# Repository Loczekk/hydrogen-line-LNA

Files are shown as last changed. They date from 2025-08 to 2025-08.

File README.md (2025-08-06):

PL below
<!-- TABLE OF CONTENTS -->

<details> <summary>Table of Contents</summary> 
  <ol> 
    <li><a href="#introduction">Introduction</a></li> 
    <li><a href="#final-parameters">Final Parameters</a></li> 
    <li><a href="#measurements">Measurements</a></li> 
  </ol> 
</details>
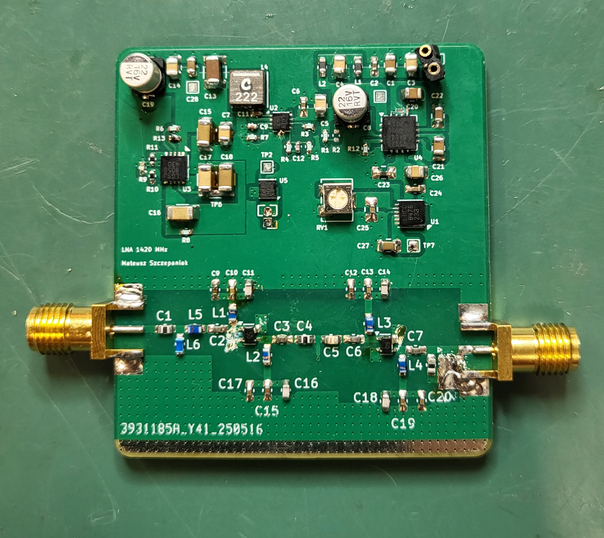
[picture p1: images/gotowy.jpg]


<!-- INTRODUCTION -->
## Introduction
The aim of the project was to design, build and test a low noise amplifier operating in the L-band. The amplifier was to meet strict requirements for gain (> 30 dB) and noise figure less than 1 dB.
A two-stage amplifier was implemented as a PCB on RF4 laminate and then subjected to detailed measurements to verify its performance. Scattering parameters, noise figure, 1 dB compression point, harmonic and third-order intermodulation distortion were measured.
Based on the results, it was concluded that the amplifier meets most of the design requirements: gain of 35.15 dB, output matching of 12.68 dB and 1-dB compression point at 3.02 dBm. Only the noise figure exceeded the assumed value and reached 1.39 dB, which, however, does not disqualify it from applications in radio astronomy.
Additionally, an automatic biasing circuit for the LNA was designed to ensure the correct power-up voltage sequence.
<p align="right">(<a href="#readme-top">back to top</a>)</p>

## Final Parameters
<h3>Key Parameters (for <strong>f = 1420 MHz</strong>)</h3>

<table>
  <thead>
    <tr>
      <th>Parameter</th>
      <th>Value</th>
      <th>Requirement</th>
    </tr>
  </thead>
  <tbody>
    <tr>
      <td>Gain</td>
      <td>35.15 dB</td>
      <td>&gt; 30 dB</td>
    </tr>
    <tr>
      <td>Noise figure</td>
      <td>1.39 dB</td>
      <td>&lt; 1 dB</td>
    </tr>
    <tr>
      <td>Output matching (<i>S<sub>22</sub></i>)</td>
      <td>12.68 dB</td>
      <td>&gt; 10 dB</td>
    </tr>
    <tr>
      <td>Compression point (<i>P<sub>1dB</sub></i>)</td>
      <td>3.02 dBm</td>
      <td>&gt; 0 dBm</td>
    </tr>
    <tr>
      <td>THD (for <i>P<sub>IN</sub></i> = –40 dBm)</td>
      <td>–47.21 dB</td>
      <td>–</td>
    </tr>
    <tr>
      <td>IP3 (for <i>P<sub>IN</sub></i> = –40 dBm)</td>
      <td>19.09 dBm</td>
      <td>–</td>
    </tr>
  </tbody>
</table>
<p align="right">(<a href="#readme-top">back to top</a>)</p>

## Measurements
<h3>S11 and S22 parameters to compare with simulate</h3>
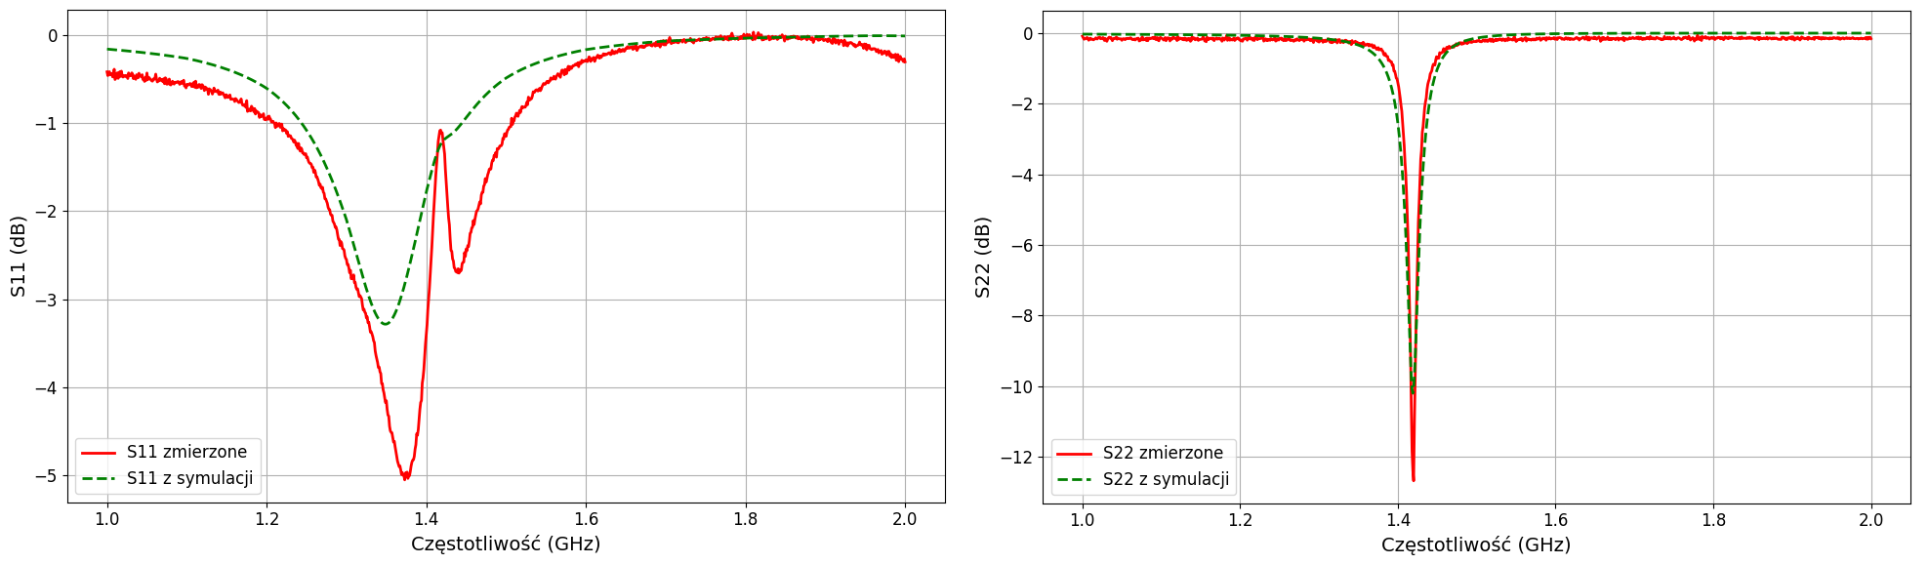
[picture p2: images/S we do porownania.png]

<h3>Gain and Noise to compare with simualation</h3>
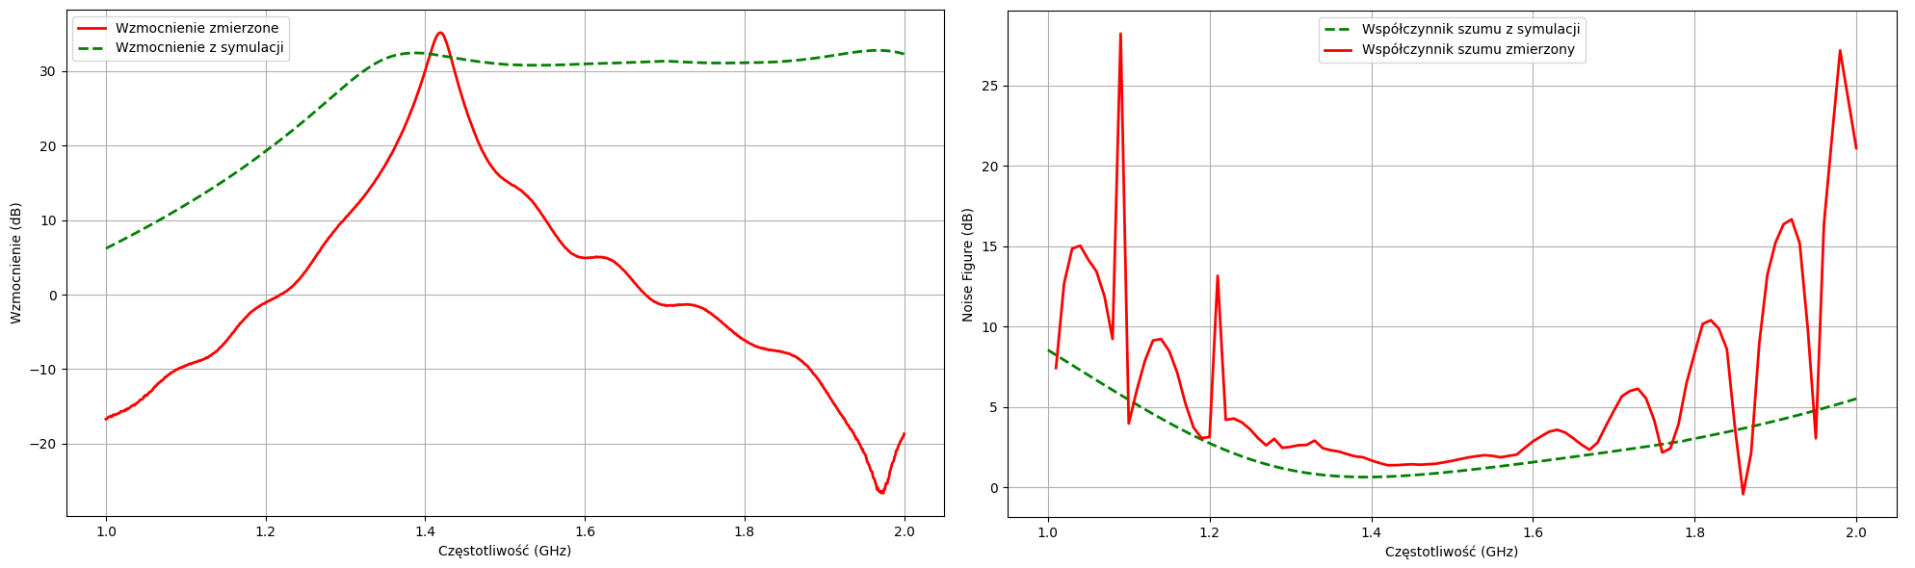
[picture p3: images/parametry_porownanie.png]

<h3>All S parameters</h3>
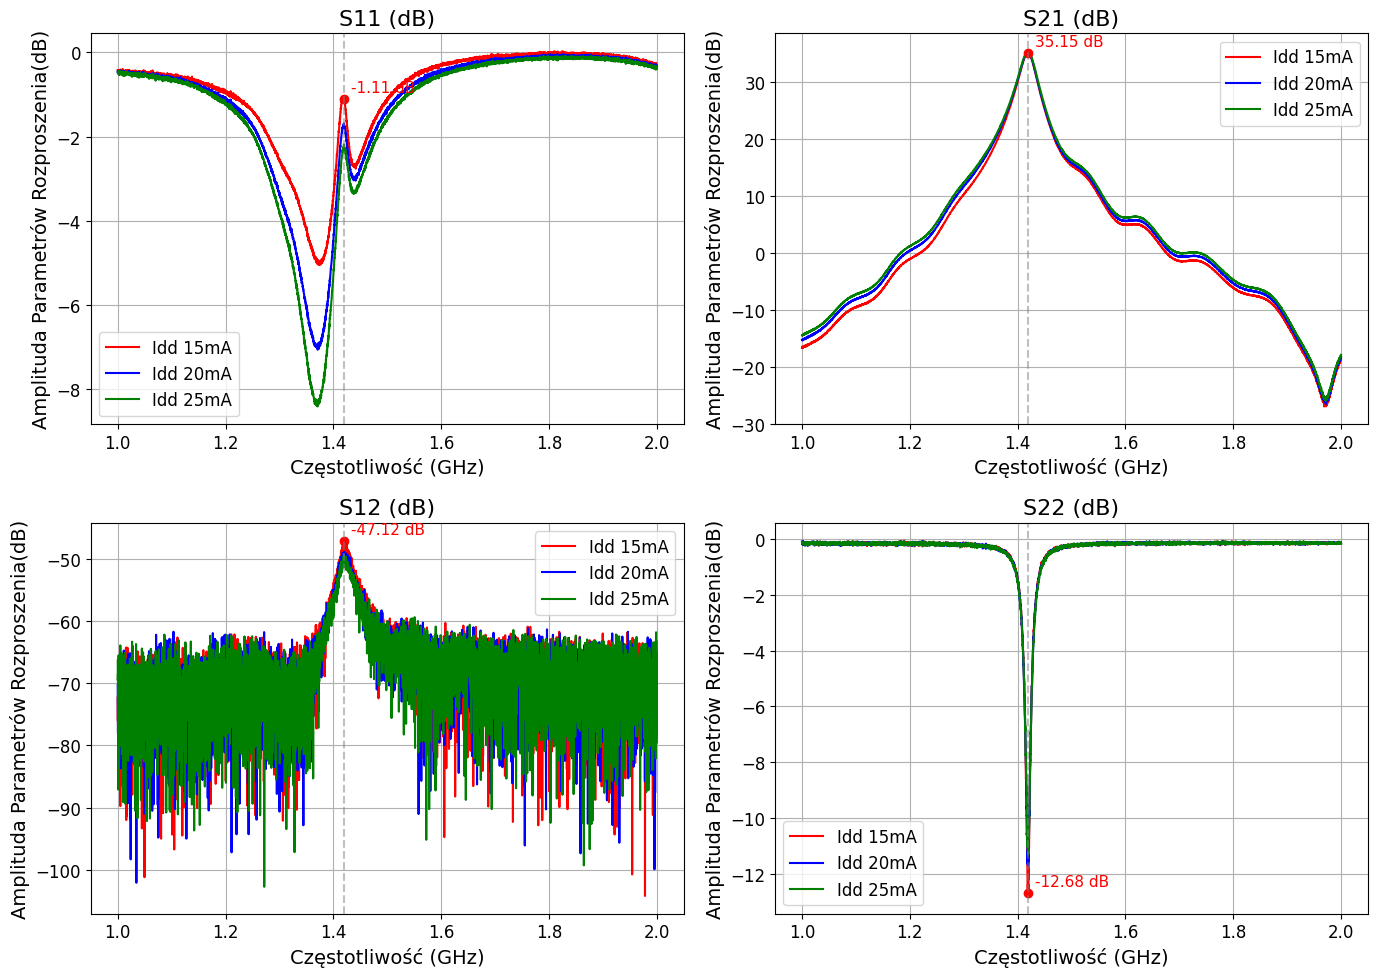
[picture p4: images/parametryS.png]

<p align="right">(<a href="#readme-top">back to top</a>)</p>

Wyniki mojej pracy inżynierskiej, całość udostępniona w formie PDF.

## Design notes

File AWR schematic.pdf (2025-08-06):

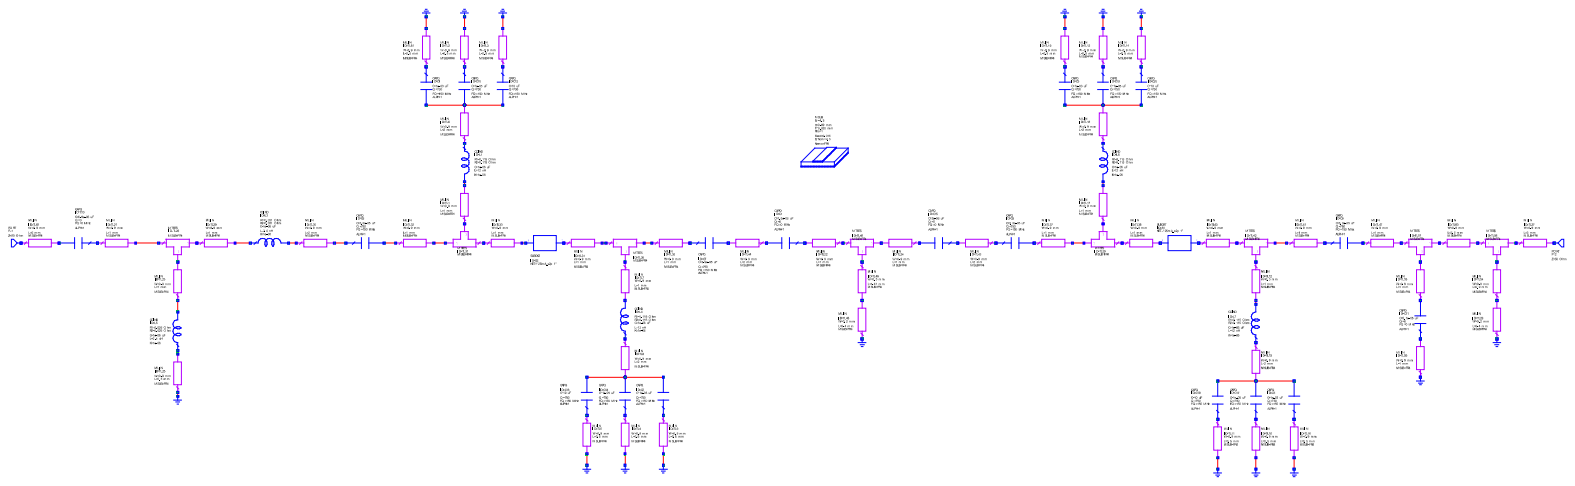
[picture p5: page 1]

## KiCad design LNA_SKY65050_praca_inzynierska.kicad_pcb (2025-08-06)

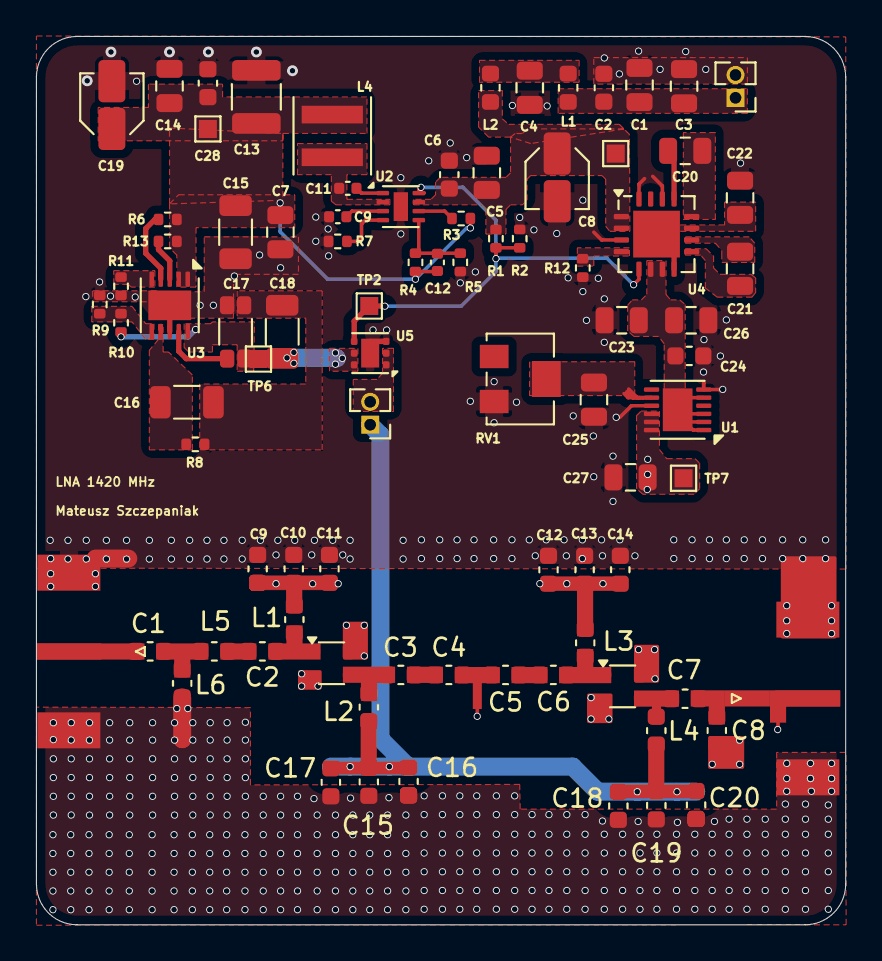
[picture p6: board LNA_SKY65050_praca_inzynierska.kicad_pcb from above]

Board: 4 copper layers, 45.0 x 49.4 mm, 82 parts (0 on the bottom side), 29 nets.

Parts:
C1, C2, C3#2, C4, C5#2, C6#2, C7, C8#2, C9#2, C10, C11, C12, C13#2, C14#2, C15#2, C16, C17#2, C18, C19, C20#2: C_0603_1608Metric
C1#2, C20, C21: 1u; C_0805_2012Metric
C2#2: 0.1u; C_0603_1608Metric
C3, C4#2, C5, C7#2, C14, C25, C26: 4,7u; C_0805_2012Metric
C6: 0,1u; C_0603_1608Metric
C8, C19#2: 22u; C_Elec_3x5.4
C9: 1u; C_0402_1005Metric
C11#2: 0,1u; C_0402_1005Metric
C12#2: 10p; C_0402_1005Metric
C13: 47u; C_1210_3225Metric
C15: C; C_1206_3216Metric
C16#2, C17: 4,7u; C_1206_3216Metric
C18#2: opt; C_1206_3216Metric
C22, C27: 10u; C_0805_2012Metric
C23: 2,2u; C_0805_2012Metric
C24: 0,01u; C_0603_1608Metric
C28: 22u; C_0603_1608Metric
J1: Conn_01x02_Pin; PinHeader_1x02_P1.27mm_Vertical
J2: Id; PinHeader_1x02_P1.27mm_Vertical
L1: FB; L_0603_1608Metric
L1#2, L2#2, L3, L4, L5, L6: C_0603_1608Metric
L2: 0; L_0603_1608Metric
L4#2: 2,2u; L_Coilcraft_XxL4020
R1, R4: 1M; R_0402_1005Metric
R2: opt; R_0402_1005Metric
R3: 100k; R_0402_1005Metric
R5: 187k; R_0402_1005Metric
R6: 200k; R_0402_1005Metric
R7: 18,2k; R_0402_1005Metric
R8, R9: 30k; R_0402_1005Metric
R10: 453k; R_0402_1005Metric
R11: 510; R_0402_1005Metric
R12: 110k; R_0402_1005Metric
R13: 0; R_0402_1005Metric
RV1: 100k; Potentiometer_Bourns_3224W_Vertical
TP1: Vin; TestPoint_Pad_1.0x1.0mm
TP2: EN; TestPoint_Pad_1.0x1.0mm
TP3: 5V; TestPoint_Pad_1.0x1.0mm
TP6: 3V; TestPoint_Pad_1.0x1.0mm
TP7: Vgg; TestPoint_Pad_1.0x1.0mm
U1: LT3094xDD; DFN-12-1EP_3x3mm_P0.45mm_EP1.65x2.38mm
U2: LT8608; DFN-8-1EP_2x2mm_P0.5mm_EP0.8x1.6mm
U3: LT3042; DFN-10-1EP_3x3mm_P0.5mm_EP1.65x2.38mm
U4: ADP5600; LFCSP-16-1EP_4x4mm_P0.65mm_EP2.6x2.6mm
U5: ADP197-02; LFCSP-6-1EP_2x2mm_P0.65mm_EP1x1.6mm

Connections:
GND: C1#2.2, C2#2.2, C3.2, C4#2.2, C5.2, C6.2, C7#2.2, C8.2, C9.2, C9#2.1, C10.1, C11.1, C12.1, C13.1, C13#2.1, C14.1, C14#2.1, C15.2, C15#2.2, C16.2, C16#2.2, C17.2, C17#2.2, C18.2, C18#2.2, C19.2, C19#2.2, C20#2.2, C22.2, C23.2, C24.2, C25.2, C26.1, C27.2, C28.2, J1.2, L6.1, R2.2, R5.1, R7.1, R8.2, R9.2, R11.2, R12.2, RV1.3, U1.6 (ILIM), U1.9 (GND), U2.9 (GND), U3.8 (GND), U3.11 (GND), U4.3 (SYNC), U4.14 (SEL2), U4.16 (GND), U5.3 (GND), U5.7 (EP)
unnamed: C4#2.1, L1.2, L2.1
unnamed: C7#2.1, C12#2.2, C13.2, C14.2, C15.1, C19#2.1, C28.1, L4#2.2, R3.2, R4.2, R6.1, R13.1, TP3.1, U3.1 (IN), U3.2 (IN)
unnamed: C1#2.1, C2#2.1, C3.1, J1.1, L1.1
unnamed: J2.2, U5.1 (VOUT), U5.2 (VOUT)
unnamed: C23.1, C24.1, C26.2, U1.1 (IN), U1.2 (IN), U1.3 (EN/UV), U1.5 (PGFB), U1.13 (IN), U4.6 (FB), U4.7 (LDO_OUT)
unnamed: C25.1, RV1.2, U1.8 (SET)
unnamed: C11#2.1, U2.1 (BST)
unnamed: R1.2, R2.1, TP2.1, U2.8 (EN/UV), U4.5 (PGOOD), U5.4 (EN)
unnamed: C12#2.1, R4.1, R5.2, U2.5 (FB)
unnamed: R3.1, U2.6 (PG)
unnamed: R7.2, U2.4 (RT)
unnamed: C11#2.2, L4#2.1, U2.2 (SW)
unnamed: C9.1, U2.3 (Vcc)
unnamed: C5.1, C6.1, C8.1, L2.2, R1.1, TP1.1, U2.7 (Vin), U4.1 (Vin), U4.2 (EN)
unnamed: R13.2, U3.3 (EN/UV)
unnamed: R11.1, U3.5 (ILIM_)
unnamed: R6.2, U3.4 (PG)
unnamed: R9.1, R10.2, U3.6 (PGFB)
unnamed: C16#2.1, R8.1, U3.7 (SET)
unnamed: C20.1, U4.12 (C1+)
unnamed: C20.2, U4.13 (C1-)
unnamed: C21.1, U4.10 (C2+)
unnamed: C21.2, U4.9 (C2-)
unnamed: C22.1, U4.8 (CPOUT), U4.11 (CPOUT), U4.17 (EP)
unnamed: R12.1, U4.4 (FREQ)
Vd_3V: C17.1, C18#2.1, R10.1, TP6.1, U3.9 (OUTS), U3.10 (OUT), U5.5 (VIN), U5.6 (VIN)
Vd_prottected: C15#2.1, C16.1, C17#2.1, C18.1, C19.1, C20#2.1, J2.1, L2#2.1, L4.1
Vgg: C9#2.2, C10.2, C11.2, C12.2, C13#2.2, C14#2.2, C27.1, L1#2.2, L3.2, TP7.1, U1.10 (OUTS), U1.11 (OUT), U1.12 (OUT)
